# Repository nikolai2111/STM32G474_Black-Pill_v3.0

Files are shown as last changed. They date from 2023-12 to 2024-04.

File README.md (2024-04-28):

<!-- Improved compatibility of back to top link: See: https://github.com/othneildrew/Best-README-Template/pull/73 -->

<!--
*** Thanks for checking out the Best-README-Template. If you have a suggestion
*** that would make this better, please fork the repo and create a pull request
*** or simply open an issue with the tag "enhancement".
*** Don't forget to give the project a star!
*** Thanks again! Now go create something AMAZING! :D
-->

<!-- PROJECT SHIELDS -->
<!--
*** I'm using markdown "reference style" links for readability.
*** Reference links are enclosed in brackets [ ] instead of parentheses ( ).
*** See the bottom of this document for the declaration of the reference variables
*** for contributors-url, forks-url, etc. This is an optional, concise syntax you may use.
*** https://www.markdownguide.org/basic-syntax/#reference-style-links
-->
[][contributors-url]
[][forks-url]
[][stars-url]
[][issues-url]
[][license-url]


<!-- PROJECT LOGO -->
<br />
<div align="center">

<h3 align="center">Black Pill v3.0 STM32G474</h3>

  <p align="center">
    The STM32-Pills are compact and convenient for prototyping, but their digital focus leaves room for exploration. The STM32G474's integration of analog and digital components opens up possibilities for creating versatile systems. For example, the integrated opamps and comparators. 
    <br />
    <a href="https://github.com/nikolai2111/STM32G474_Black-Pill_v3.0"><strong>Explore the docs »</strong></a>
    <br />
    <br />
    <a href="https://github.com/nikolai2111/STM32G474_Black-Pill_v3.0">View Demo</a>
    ·
    <a href="https://github.com/nikolai2111/STM32G474_Black-Pill_v3.0/issues/new?labels=bug&template=bug-report---.md">Report Bug</a>
    ·
    <a href="https://github.com/nikolai2111/STM32G474_Black-Pill_v3.0/issues/new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">Request Feature</a>
  </p>
</div>

<!-- TABLE OF CONTENTS -->
<details>
  <summary>Table of Contents</summary>
  <ol>
    <li>
      <a href="#about-the-project">About The Project</a>
      <ul>
        <li><a href="#built-with">Built With</a></li>
      </ul>
    </li>
    <li>
      <a href="#getting-started">Getting Started</a>
      <ul>
        <li><a href="#prerequisites">Prerequisites</a></li>
        <li><a href="#installation">Installation</a></li>
      </ul>
    </li>
    <li><a href="#usage">Usage</a></li>
    <li><a href="#roadmap">Roadmap</a></li>
    <li><a href="#contributing">Contributing</a></li>
    <li><a href="#license">License</a></li>
    <li><a href="#contact">Contact</a></li>
  </ol>
</details>

<!-- ABOUT THE PROJECT -->
## About The Project

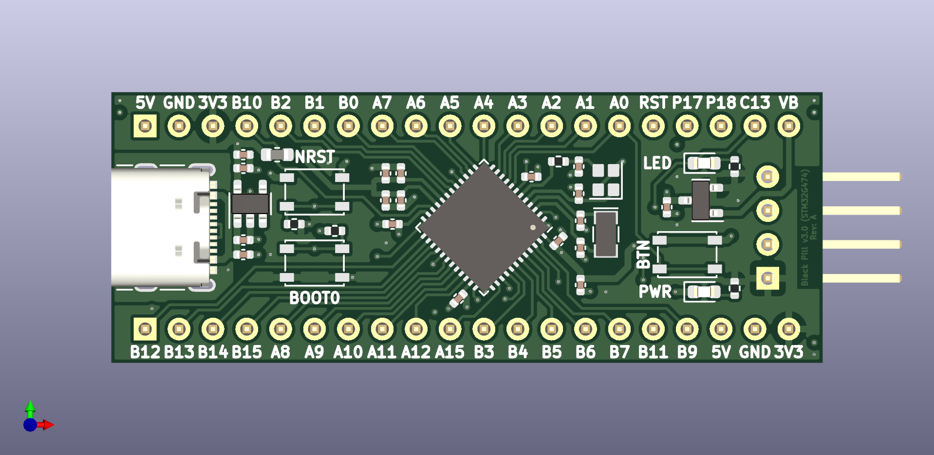
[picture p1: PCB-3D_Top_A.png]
Product Name Screen Shot
[](https://www.tindie.com/products/nikolai2111/black-pill-v30-stm32g474/)

I find the compact and versatile STM32-Pills (Blue and Black) intriguing due to their ease of use for various applications. They seamlessly integrate into hardware prototypes, simplifying the process of testing ideas. However, I’ve noticed that the existing Black Pills primarily focus on digital tasks.

On the other hand, the STM32G474 stands out as a fascinating microcontroller that bridges the gap between the digital and analog worlds. What piques my interest are its integrated analog components, such as op-amps and comparators, coupled with digital interfaces. This combination offers an exciting opportunity to develop systems that seamlessly blend both digital and analog functionalities.

In summary, while the compact and convenient Pills are fascinating tools for rapid prototyping, their current digital focus leaves room for exploration. In contrast, the STM32G474’s integration of analog and digital components opens up exciting possibilities for creating versatile, boundary-pushing systems.

<p align="right">(<a href="#readme-top">back to top</a>)</p>

### Built With

* [][Kicad-url]

<p align="right">(<a href="#readme-top">back to top</a>)</p>

<!-- GETTING STARTED -->
## Getting Started

### Prerequisites

Install KiCad 8.0 on your computer.

### Installation

ToDo:
1. Clone the repo to your STM32CubeIDE workspace
   ```sh
   git clone https://github.com/nikolai2111/STM32G474_Black-Pill_v3.0.git
   ```
2. Navigate to the the `src` folder.
3. Open the [project file](src/STM32G474_Black-Pill_v3.0.kicad_pro).

<p align="right">(<a href="#readme-top">back to top</a>)</p>

<!-- USAGE EXAMPLES -->
## Usage

Use this dev board with the template from [this repo](https://github.com/nikolai2111/STM32G474_Black-Pill_v3.0_Template). It's an example file.

<p align="right">(<a href="#readme-top">back to top</a>)</p>

<!-- ROADMAP -->
## Roadmap

- [ ] SW: Publish HAL template for this board.
- [ ] SW: Add LL template for this board.

See the [open issues](https://github.com/nikolai2111/STM32G474_Black-Pill_v3.0/issues) for a full list of proposed features (and known issues).

<p align="right">(<a href="#readme-top">back to top</a>)</p>

<!-- CONTRIBUTING -->
## Contributing

Contributions are what make the open source community such an amazing place to learn, inspire, and create. Any contributions you make are **greatly appreciated**.

If you have a suggestion that would make this better, please fork the repo and create a pull request. You can also simply open an issue with the tag "enhancement".
Don't forget to give the project a star! Thanks again!

1. Fork the Project
2. Create your Feature Branch (`git checkout -b feature/AmazingFeature`)
3. Commit your Changes (`git commit -m 'Add some AmazingFeature'`)
4. Push to the Branch (`git push origin feature/AmazingFeature`)
5. Open a Pull Request

<p align="right">(<a href="#readme-top">back to top</a>)</p>

<!-- LICENSE -->
## License

Distributed under the CERN-OHL-P-2.0 License. See `LICENSE.txt` for more information.

<p align="right">(<a href="#readme-top">back to top</a>)</p>

<!-- CONTACT -->
## Contact

Nikolai Zoller - nikolai.zoller@hotmail.com

Project Link: [https://github.com/nikolai2111/STM32G474_Black-Pill_v3.0](https://github.com/nikolai2111/STM32G474_Black-Pill_v3.0)

<p align="right">(<a href="#readme-top">back to top</a>)</p>

---
Source: [Best-README-Template](https://github.com/othneildrew/Best-README-Template)

<!-- MARKDOWN LINKS & IMAGES -->
<!-- https://www.markdownguide.org/basic-syntax/#reference-style-links -->
[contributors-shield]: https://img.shields.io/github/contributors/nikolai2111/STM32G474_Black-Pill_v3.0.svg?style=for-the-badge
[contributors-url]: https://github.com/nikolai2111/STM32G474_Black-Pill_v3.0/graphs/contributors
[forks-shield]: https://img.shields.io/github/forks/nikolai2111/STM32G474_Black-Pill_v3.0.svg?style=for-the-badge
[forks-url]: https://github.com/nikolai2111/STM32G474_Black-Pill_v3.0/network/members
[stars-shield]: https://img.shields.io/github/stars/nikolai2111/STM32G474_Black-Pill_v3.0.svg?style=for-the-badge
[stars-url]: https://github.com/nikolai2111/STM32G474_Black-Pill_v3.0/stargazers
[issues-shield]: https://img.shields.io/github/issues/nikolai2111/STM32G474_Black-Pill_v3.0.svg?style=for-the-badge
[issues-url]: https://github.com/nikolai2111/STM32G474_Black-Pill_v3.0/issues
[license-shield]: https://img.shields.io/github/license/nikolai2111/STM32G474_Black-Pill_v3.0.svg?style=for-the-badge
[license-url]: https://github.com/nikolai2111/STM32G474_Black-Pill_v3.0/blob/master/LICENSE.txt
[product-screenshot]: PCB-3D_Top_A.png
[Kicad-url]: https://www.kicad.org/

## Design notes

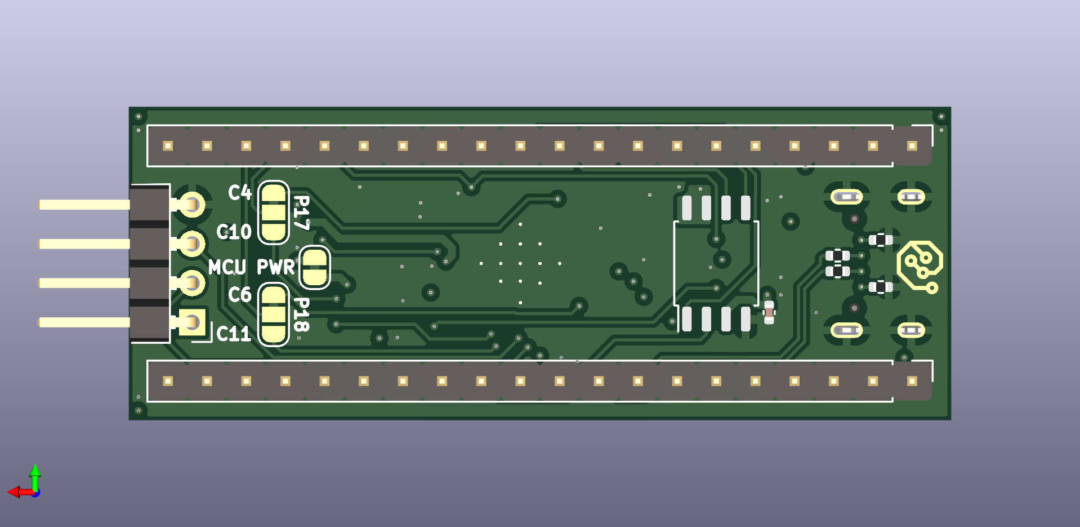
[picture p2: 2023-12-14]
PCB-3D_Bot_A.png

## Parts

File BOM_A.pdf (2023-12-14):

Reference | Value | Footprint | Manufacturer Part no. | Vendor | Vendor Part No. | Qty
C101, C104, C108-C110, C112, C114, C115, C119, C120 | 100nF | Capacitor_SMD:C_0402_1005Metric | GRM155R71C104KA88D | Digikey | 490-3261-1-ND | 10
C102, C103, C105, C106 | 6pF | Capacitor_SMD:C_0402_1005Metric | GRM1555C1H6R0BA01D | Digikey | 490-8221-1-ND | 4
C107 | 10µF | Capacitor_SMD:C_0402_1005Metric | GRM155R60J106ME15D | Digikey | 490-13238-1-ND | 1
C113, C116-C118 | 1µF | Capacitor_SMD:C_0402_1005Metric | GRM155C81C105KE11D | Digikey | 490-12700-1-ND | 4
D101 | red | LED_SMD:LED_0603_1608Metric | LTST-C190KRKT | Digikey | 160-1436-1-ND | 1
D102 | BAT54C | Package_TO_SOT_SMD:SOT-23 | BAT54C | Digikey | 4878-BAT54CCT-ND | 1
D103 | green | LED_SMD:LED_0603_1608Metric | LTST-C190KGKT | Digikey | 160-1435-1-ND | 1
J101 | USB_C_Receptacle_USB2.0 | Connector_USB:USB_C_Receptacle_GCT_USB4105-xx-A_16P_TopMnt_Horizontal | USB4105-GF-A | Digikey | 2073-USB4105-GF-ACT-ND | 1
J102, J103 | Conn_01x20 | Connector_PinHeader_2.54mm:PinHeader_1x20_P2.54mm_Vertical | - | From stock | - | 2
J104 | Conn_01x04 | Connector_PinHeader_2.54mm_User:PinHeader_1x04_P2.54mm_Horizontal_Board_Edge | - | From stock | - | 1
L101 | 10µH | Inductor_SMD:L_0603_1608Metric | MLZ1608M100WT000 | Digikey | 445-6389-1-ND | 1
R101, R102 | 5.1k | Resistor_SMD:R_0402_1005Metric | RC0402FR-075K1L | Digikey | 311-5.10KLRCT-ND | 2
R103, R108 | 10k | Resistor_SMD:R_0402_1005Metric | RC0402FR-0710KL | Digikey | 311-10.0KLRCT-ND | 2
R104, R105 | 10R | Resistor_SMD:R_0402_1005Metric | RC0402FR-0710RL | Digikey | 311-10.0LRCT-ND | 2
R106 | 0R | Resistor_SMD:R_0402_1005Metric | RC0402FR-070RL | Digikey | 311-0.0LRCT-ND | 1
R107, R109 | 100R | Resistor_SMD:R_0402_1005Metric | RC0402FR-07100RL | Digikey | 311-100LRCT-ND | 2
SW101-SW103 | SW_Push | Button_Switch_SMD:SW_SPST_PTS810 | PTS810 SJK 250 SMTR LFS | Digikey | CKN10503CT-ND | 3
U101 | W25Q32JVSS | Package_SO:SOIC-8_5.23x5.23mm_P1.27mm | W25Q32JVSSIQ | Digikey | W25Q32JVSSIQ-ND | 1
U102 | STM32G474CEUx | Package_DFN_QFN:QFN-48-1EP_7x7mm_P0.5mm_EP5.6x5.6mm | STM32G474CEU6 | Digikey | 497-STM32G474CEU6-ND | 1
U103 | AP7343xx | Package_TO_SOT_SMD:SOT-23-5 | AP7343-33W5-7 | Digikey | AP7343-33W5-7DICT-ND | 1
Y101 | 24MHz | Crystal:Crystal_SMD_SeikoEpson_FA128-4Pin_2.0x1.6mm | NX2016SA-24MHZ-EXS00A-CS10820 | Digikey | 644-1365-1-ND | 1
Y102 | 32.768kHz | Crystal:Crystal_SMD_MicroCrystal_CC7V-T1A-2Pin_3.2x1.5mm | NX3215SA-32.768KHZ-EXS00A-MU00525 | Digikey | 644-1386-1-ND | 1

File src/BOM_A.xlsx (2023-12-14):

Reference | Value | Footprint | Datasheet | Manufacturer Part no. | Vendor | Vendor Part No. | Qty
C101, C104, C108-C110, C112, C114, C115, C119, C120 | 100nF | Capacitor_SMD:C_0402_1005Metric | ~ | GRM155R71C104KA88D | Digikey | 490-3261-1-ND | 10
C102, C103, C105, C106 | 6pF | Capacitor_SMD:C_0402_1005Metric | ~ | GRM1555C1H6R0BA01D | Digikey | 490-8221-1-ND | 4
C107 | 10µF | Capacitor_SMD:C_0402_1005Metric | ~ | GRM155R60J106ME15D | Digikey | 490-13238-1-ND | 1
C113, C116-C118 | 1µF | Capacitor_SMD:C_0402_1005Metric | ~ | GRM155C81C105KE11D | Digikey | 490-12700-1-ND | 4
D101 | red | LED_SMD:LED_0603_1608Metric | ~ | LTST-C190KRKT | Digikey | 160-1436-1-ND | 1
D102 | BAT54C | Package_TO_SOT_SMD:SOT-23 | http://www.diodes.com/_files/datasheets/ds11005.pdf | BAT54C | Digikey | 4878-BAT54CCT-ND | 1
D103 | green | LED_SMD:LED_0603_1608Metric | ~ | LTST-C190KGKT | Digikey | 160-1435-1-ND | 1
J101 | USB_C_Receptacle_USB2.0 | Connector_USB:USB_C_Receptacle_GCT_USB4105-xx-A_16P_TopMnt_Horizontal | https://www.usb.org/sites/default/files/documents/usb_type-c.zip | USB4105-GF-A | Digikey | 2073-USB4105-GF-ACT-ND | 1
J102, J103 | Conn_01x20 | Connector_PinHeader_2.54mm:PinHeader_1x20_P2.54mm_Vertical | ~ | - | From stock | - | 2
J104 | Conn_01x04 | Connector_PinHeader_2.54mm_User:PinHeader_1x04_P2.54mm_Horizontal_Board_Edge | ~ | - | From stock | - | 1
JP101, JP102 | SolderJumper_3_Bridged12 | Jumper:SolderJumper-3_P1.3mm_Bridged12_RoundedPad1.0x1.5mm_NumberLabels | ~ | - | - | - | 2
JP103 | SolderJumper_2_Bridged | Jumper:SolderJumper-2_P1.3mm_Bridged_RoundedPad1.0x1.5mm | ~ | - | - | - | 1
L101 | 10µH | Inductor_SMD:L_0603_1608Metric | ~ | MLZ1608M100WT000 | Digikey | 445-6389-1-ND | 1
R101, R102 | 5.1k | Resistor_SMD:R_0402_1005Metric | ~ | RC0402FR-075K1L | Digikey | 311-5.10KLRCT-ND | 2
R103, R108 | 10k | Resistor_SMD:R_0402_1005Metric | ~ | RC0402FR-0710KL | Digikey | 311-10.0KLRCT-ND | 2
R104, R105 | 10R | Resistor_SMD:R_0402_1005Metric | ~ | RC0402FR-0710RL | Digikey | 311-10.0LRCT-ND | 2
R106 | 0R | Resistor_SMD:R_0402_1005Metric | ~ | RC0402FR-070RL | Digikey | 311-0.0LRCT-ND | 1
R107, R109 | 100R | Resistor_SMD:R_0402_1005Metric | ~ | RC0402FR-07100RL | Digikey | 311-100LRCT-ND | 2
SW101-SW103 | SW_Push | Button_Switch_SMD:SW_SPST_PTS810 | ~ | PTS810 SJK 250 SMTR LFS | Digikey | CKN10503CT-ND | 3
U101 | W25Q32JVSS | Package_SO:SOIC-8_5.23x5.23mm_P1.27mm | http://www.winbond.com/resource-files/w25q32jv%20revg%2003272018%20plus.pdf | W25Q32JVSSIQ | Digikey | W25Q32JVSSIQ-ND | 1
U102 | STM32G474CEUx | Package_DFN_QFN:QFN-48-1EP_7x7mm_P0.5mm_EP5.6x5.6mm | https://www.st.com/resource/en/datasheet/stm32g474ce.pdf | STM32G474CEU6 | Digikey | 497-STM32G474CEU6-ND | 1
U103 | AP7343xx | Package_TO_SOT_SMD:SOT-23-5 | https://www.diodes.com/assets/Datasheets/AP7343.pdf | AP7343-33W5-7 | Digikey | AP7343-33W5-7DICT-ND | 1
Y101 | 24MHz | Crystal:Crystal_SMD_SeikoEpson_FA128-4Pin_2.0x1.6mm | ~ | NX2016SA-24MHZ-EXS00A-CS10820 | Digikey | 644-1365-1-ND | 1
Y102 | 32.768kHz | Crystal:Crystal_SMD_MicroCrystal_CC7V-T1A-2Pin_3.2x1.5mm | ~ | NX3215SA-32.768KHZ-EXS00A-MU00525 | Digikey | 644-1386-1-ND | 1

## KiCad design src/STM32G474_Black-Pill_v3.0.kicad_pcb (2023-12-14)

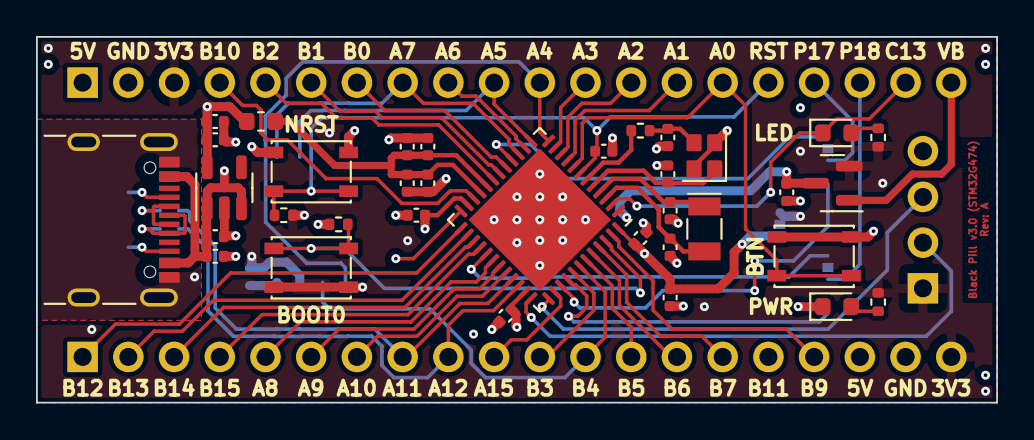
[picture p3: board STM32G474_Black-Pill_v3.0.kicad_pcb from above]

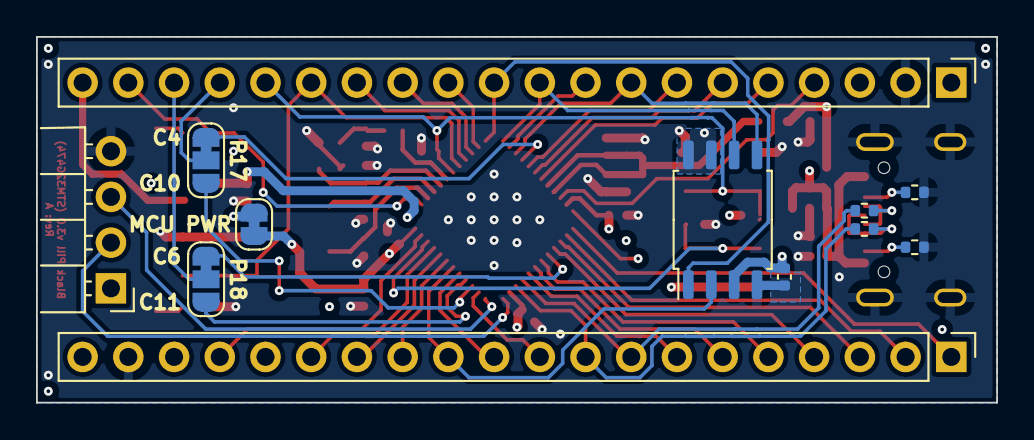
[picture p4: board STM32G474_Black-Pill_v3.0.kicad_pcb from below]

Board: 4 copper layers, 53.3 x 20.3 mm, 47 parts (12 on the bottom side), 58 nets.

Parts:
C101, C104, C108, C109, C110, C112, C114, C115, C119, C120: 100nF; C_0402_1005Metric
C102, C103, C105, C106: 6pF; C_0402_1005Metric
C107: 10µF; C_0402_1005Metric
C113, C116, C117, C118: 1µF; C_0402_1005Metric
D101: red; LED_0603_1608Metric
D102: BAT54C; SOT-23
D103: green; LED_0603_1608Metric
J101: USB_C_Receptacle_USB2.0; USB_C_Receptacle_GCT_USB4105-xx-A_16P_TopMnt_Horizontal
J102, J103: Conn_01x20; PinHeader_1x20_P2.54mm_Vertical
J104: Conn_01x04; PinHeader_1x04_P2.54mm_Horizontal_Board_Edge
JP101, JP102: SolderJumper_3_Bridged12; SolderJumper-3_P1.3mm_Bridged12_RoundedPad1.0x1.5mm_NumberL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
JP103: SolderJumper_2_Bridged; SolderJumper-2_P1.3mm_Bridged_RoundedPad1.0x1.5mm
L101: 10µH; L_0603_1608Metric
R101, R102: 5.1k; R_0402_1005Metric
R103, R108: 10k; R_0402_1005Metric
R104, R105: 10R; R_0402_1005Metric
R106: 0R; R_0402_1005Metric
R107, R109: 100R; R_0402_1005Metric
SW101, SW102, SW103: SW_Push; SW_SPST_PTS810
U101: W25Q32JVSS; SOIC-8_5.23x5.23mm_P1.27mm
U102: STM32G474CEUx; QFN-48-1EP_7x7mm_P0.5mm_EP5.6x5.6mm
U103: AP7343xx; SOT-23-5
Y101: 24MHz; Crystal_SMD_SeikoEpson_FA128-4Pin_2.0x1.6mm
Y102: 32.768kHz; Crystal_SMD_MicroCrystal_CC7V-T1A-2Pin_3.2x1.5mm

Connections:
+3.3V: C101.1, C115.1, C116.1, D102.2, J102.20, J103.3, J104.1, JP103.2 (B), L101.1, R103.1, R107.1, R109.1, SW102.2, U101.3 (IO2), U101.7 (IO3), U101.8 (VCC), U103.5 (OUT)
+5V: C113.1, C114.1, J101.A4 (VBUS), J101.A9 (VBUS), J101.B4 (VBUS), J101.B9 (VBUS), J102.18, J103.1, U103.1 (IN), U103.3 (EN)
/+3.3V_{MCU}: C107.1, C108.1, C109.1, C110.1, JP103.1 (A), U102.23 (VDD), U102.35 (VDD), U102.48 (VDD)
/PA0: J103.15, SW103.2, U102.8 (PA0)
/PA1: J103.14, U102.9 (PA1)
/PA2: J103.13, U102.10 (PA2)
/PA3: J103.12, U102.11 (PA3)
/PA4: J103.11, U101.1 (~CS), U102.12 (PA4)
/PA5: J103.10, U101.6 (CLK), U102.13 (PA5)
/PA6: J103.9, U102.14 (PA6)
/PA7: J103.8, U101.5 (DI(IO0)), U102.15 (PA7)
/PA8: J102.5, U102.30 (PA8)
/PA9: J102.6, U102.31 (PA9)
/PA10: J102.7, U102.32 (PA10)
/PA11: J102.8, R104.2, U102.33 (PA11)
/PA12: J102.9, R105.2, U102.34 (PA12)
/PA15: J102.10, U102.38 (PA15)
/PB0: J103.7, U102.17 (PB0)
/PB1: J103.6, U102.18 (PB1)
/PB2: J103.5, U102.19 (PB2)
/PB3: J102.11, U102.41 (PB3)
/PB4: J102.12, U101.2 (DO(IO1)), U102.42 (PB4)
/PB5: J102.13, U102.43 (PB5)
/PB6: J102.14, U102.44 (PB6)
/PB7: J102.15, U102.45 (PB7)
/PB8: R108.1, SW102.1, U102.46 (PB8)
/PB9: J102.17, U102.47 (PB9)
/PB10: J103.4, U102.22 (PB10)
/PB11: J102.16, U102.24 (PB11)
/PB12: J102.1, U102.25 (PB12)
/PB13: J102.2, U102.26 (PB13)
/PB14: J102.3, U102.27 (PB14)
/PB15: J102.4, U102.28 (PB15)
/PC4: JP101.1 (A), U102.16 (PC4)
/PC6: JP102.1 (A), U102.29 (PC6)
/PC10: JP101.3 (B), U102.39 (PC10)
/PC11: JP102.3 (B), U102.40 (PC11)
/PC13: D103.1 (K), J103.19, U102.2 (PC13)
/PC14: C105.2, U102.3 (PC14), Y102.2
/PC15: C106.2, U102.4 (PC15), Y102.1
/Pin17: J103.17, JP101.2 (C)
/Pin18: J103.18, JP102.2 (C)
/SWCLK: J104.3, U102.37 (PA14)
/SWDIO: J104.2, U102.36 (PA13)
GND: C101.2, C102.1, C103.1, C104.2, C105.1, C106.1, C107.2, C108.2, C109.2, C110.2, C112.2, C113.2, C114.2, C115.2, C116.2, C117.1, C118.1, C119.1, C120.1, D101.1 (K), J101.A1 (GND), J101.A12 (GND), J101.B1 (GND), J101.B12 (GND), J101.S1 (SHIELD), J102.19, J103.2, J104.4, R101.2, R102.2, R108.2, SW101.1, SW103.1, U101.4 (GND), U102.49 (VSS), U103.2 (GND), Y101.2, Y101.4
NRST: C104.1, J103.16, R103.2, SW101.2, U102.7 (PG10)
unnamed: C103.2, R106.2, Y101.3
unnamed: D101.2 (A), R107.2
unnamed: D103.2 (A), R109.2
unnamed: J101.A5 (CC1), R101.1
unnamed: J101.B5 (CC2), R102.1
unnamed: J101.A6 (D+), J101.B6 (D+), R105.1
unnamed: J101.A7 (D-), J101.B7 (D-), R104.1
unnamed: C102.2, U102.5 (PF0), Y101.1
unnamed: R106.1, U102.6 (PF1)
VB: D102.1, J103.20
VBAT: C112.1, D102.3, U102.1 (VBAT)
VDDA: C117.2, C118.2, C119.2, C120.2, L101.2, U102.20 (VREF+), U102.21 (VDDA)

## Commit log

2023-10-23 Add: KiCad template to the project
    [STM32G474_Black-Pill_v3.0.kicad_pcb, STM32G474_Black-Pill_v3.0.kicad_sch]
2023-10-23 Add: Schematic to the project. Also added some documents.
    [STM32G474_Black-Pill_v3.0.kicad_sch]
2023-10-24 Mod: Schematic, added manufacturer no. and vendor no.
    [STM32G474_Black-Pill_v3.0.kicad_sch]
2023-10-24 Add: PCB Layout and modified schematic to suit the PCB needs
    [STM32G474_Black-Pill_v3.0.kicad_pcb, STM32G474_Black-Pill_v3.0.kicad_sch]
2023-10-24 Add: Exported PDFs
    [STM32G474_Black-Pill_v3.0.kicad_pcb]
2023-11-12 Mod: STM32G474_Black-Pill_v3.0.kicad_sch, changed alignment of the PA1 label.
    [STM32G474_Black-Pill_v3.0.kicad_sch]
2023-11-12 Mod: STM32G474_Black-Pill_v3.0.kicad_pcb, changed footprint of STM32G474 and the whole PCB has to be adjusted.
    [STM32G474_Black-Pill_v3.0.kicad_pcb, STM32G474_Black-Pill_v3.0.kicad_sch]
2023-11-13 Mod: PCB and Schematic, re-exported all files.
    [STM32G474_Black-Pill_v3.0.kicad_pcb, STM32G474_Black-Pill_v3.0.kicad_sch]
2023-11-13 Add: Production data
    [BOM_A.xlsx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]
2023-11-13 Add: JLCPCB Database
    [STM32G474_Black-Pill_v3.0.kicad_pcb]
2023-11-28 Mod: Moved U102 on the PCB to the programming headers. Re-exported all the files.
    [STM32G474_Black-Pill_v3.0-B_Cu.gbr, STM32G474_Black-Pill_v3.0-B_Mask.gbr, STM32G474_Black-Pill_v3.0-B_Paste.gbr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]
2023-11-28 Mod: gitignore files, added zipped gerber files.
2023-11-28 Mod: STM32G474_Black-Pill_v3.0.kicad_sch, updated BOM and re-exported BOM_A.xlsx.
    [BOM_A.xlsx, STM32G474_Black-Pill_v3.0.kicad_sch]
2023-11-28 Fix: Issue with to small annular ring.
    [STM32G474_Black-Pill_v3.0-B_Cu.gbr, STM32G474_Black-Pill_v3.0-B_Mask.gbr, STM32G474_Black-Pill_v3.0-B_Paste.gbr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]
2023-12-14 Mod: Schematic_A.pdf, renamed VREF to VDDA
    [STM32G474_Black-Pill_v3.0-B_Cu.gbr, STM32G474_Black-Pill_v3.0-B_Mask.gbr, STM32G474_Black-Pill_v3.0-B_Paste.gbr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]
2023-12-14 Mod: Moved BOM_A.xlsx to source and exported BOM_A.pdf to the repo root folder.
    [BOM_A.xlsx]
2024-01-27 Mod: Ignored gerbers directory and added the whole finished ZIP
    [STM32G474_Black-Pill_v3.0-B_Cu.gbr, STM32G474_Black-Pill_v3.0-B_Mask.gbr, STM32G474_Black-Pill_v3.0-B_Paste.gbr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]
2024-01-27 Add: STM32G474_Black-Pill_v3.0_panel.kicad_pcb, this is a generated panel with 2x5 pcs.
